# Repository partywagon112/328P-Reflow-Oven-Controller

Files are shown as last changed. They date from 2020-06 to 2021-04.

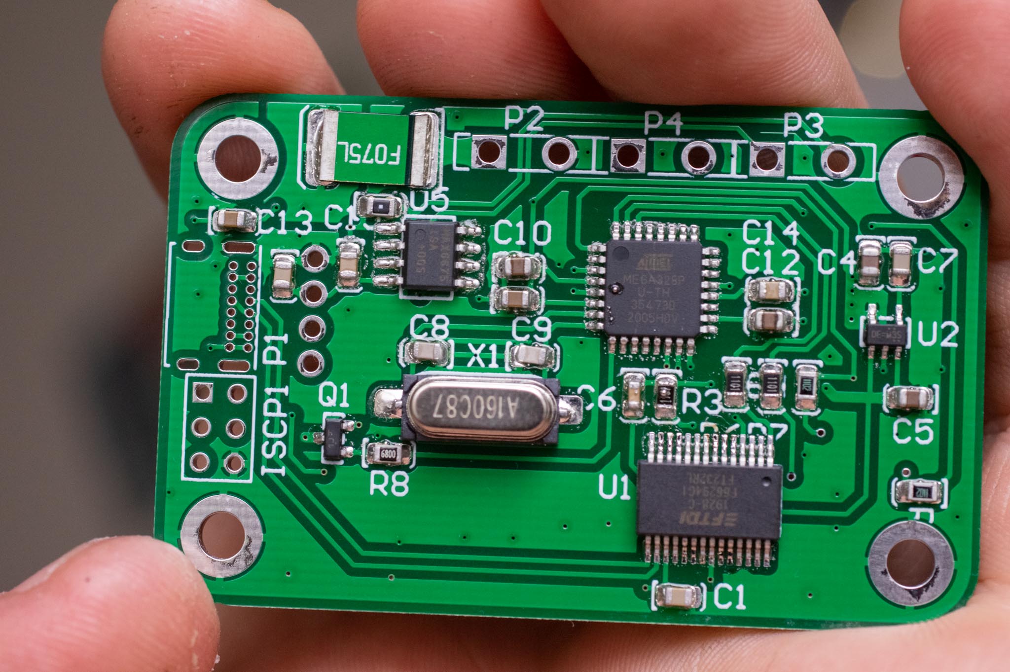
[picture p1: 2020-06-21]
Result.jpg

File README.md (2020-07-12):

# Readme

1. Originally based on ROCKETSCREAM project. Available: https://github.com/rocketscream/Reflow-Oven-Controller
2. PCB designed in altium with the use of the Team Swinburne ts_20 altium library. Available: https://github.com/Team-Swinburne/ts_20-pcb-development
3. Similar to, though heavily modifed from the original project to make it more compact.

# Known Issues and workarounds because there ait going to be another one of these things for a while
- Possible issue with backfeed via USB, cut trace to USB if required. Not generally necessary. 
- USB works C->A, but not C->C. Definite compliance issue.
- Very poor grounding between four corners. Fixed by using a conductive PLA or conductive tape within enclosure.

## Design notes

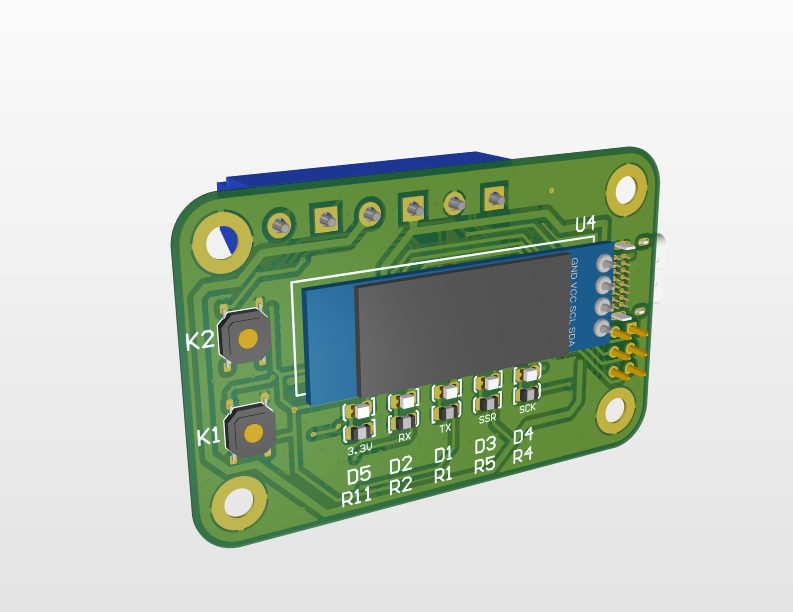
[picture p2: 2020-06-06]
Render.png

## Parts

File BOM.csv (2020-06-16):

Comment | Description | Designator | Footprint | LibRef | Quantity | Digikey Part Number
100nF |  | C1, C6, C13, C14, C15 | 805 | GCM21BR71H104KA37L | 5 | 490-6064-1-ND
4.7uF |  | C3, C11 | 805 | GCM21BR61A475KA37L | 2
1uF |  | C4, C5, C10, C12 | 805 | AC0805KKX7R8BB105 | 4
10nF |  | C7 | 805 | GCM2195C1H103JA16D | 1 | 490-4783-1-ND
22pF |  | C8, C9 | 805 | GRM21A5C2E220JW01D | 2 | 490-5534-1-ND
Orange | Orange LED Indication - Discrete 1.75V 0805 (2012 Metric) | D1 | 0805 LED | SML-211DTT86 | 1 | 511-1291-1-ND
Green | Green LED Indication - Discrete 1.75V 0805 (2012 Metric) | D2 | 0805 LED | SML-210FTT86 | 1 | 511-1285-1-ND
Red | Red LED Indication - Discrete 1.75V 0805 (2012 Metric) | D3, D5 | 0805 LED | SML-210LTT86 | 2 | 511-1286-1-ND
Blue | LED BLUE CLEAR 2012 SMD | D4 | 0805 LED | SML-MN2BCTT86C | 1 | 846-1207-1-ND
0ZCF0100AF2A | PTC RESET FUSE 60V 1A 292 | F1 | 2920 | 0ZCF0100AF2A | 1 | 507-2070-1-ND
TS-1187A-C-D-B | TACTILE SWITCHES SPST 5.10MM X 5.10MM 0.80MM SMD ROHS | K1, K2 | XKB SW-4.5 | TS-1187A-C-D-B | 2
USB4085-GF-A | USB - C (Type - C) USB 2.0 Receptacle Connector 16 Position Through Hole, Right Angle | P1 | USB4085-GF-A | USB4085-GF-A | 1 | 2073-USB4085-GF-ACT-ND
5.08mm |  | P2, P3, P4 | TH 5.08mm Header 1x2 | 1760510000 | 3 | 281-1882-ND
BC817-16LT1 | 300mW BJT NPN Transistor | Q1 | ON SOT-23 BJT | BC817-16LT1 | 1 | BC817-16LT1OSTR-ND
1k |  | R1, R2, R3, R4, R5, R6, R7, R11 | 805 | RC0805FR071KL | 8 | 311-1.00KCRCT-ND
680R |  | R8 | 805 | RC0805FR07680RL | 1 | 311-680CRCT-ND
10k |  | R9, R10 | 805 | RC0805FR0710KL | 2 | 311-10.0KCRCT-ND
0R |  | R12 | 805 | RC0805FR070RL | 1 | 311-0.0CRCT-ND
FT232RL | USB Bridge, USB to UART USB 2.0 UART Interface 28-SSOP | U1 | FTDI 28-SSOP | FT232RL | 1 | 768-1007-1-ND
RT9193-33GB | IC REG LINEAR 3.3V 300MA SOT23-5 | U2 | RICHTEK SOT-23-5 | RT9193-33GB | 1 | 1028-1014-1-ND
ATMEGA 328P-AU | AVR AVR® ATmega Microcontroller IC 8-Bit 20MHz 32KB (16K x 16) FLASH 32-TQFP (7x7) | U3 | ATMEL TQFP-32 | ATMEGA 328P-AU | 1 | ATMEGA328P-AU-ND
SSD1306 128x32 | AU 0.91 IIC I2C OLED LCD Display Module 128x32 for Arduino PIC SSD1306 3.3V~5V" | U4 | IIC 128x32 OLED | SSD1306 128x32 | 1
MAX6675 | IC THERMOCOUP TO DGTL 8-SOIC | U5 | MI 8-SOIC | MAX6675 | 1 | MAX6675ISA+-ND
=Value"" |  | X1 | Abracon HC-49/US | ABLS-16.000MHZ-B4-T | 1 | 535-10226-1-ND

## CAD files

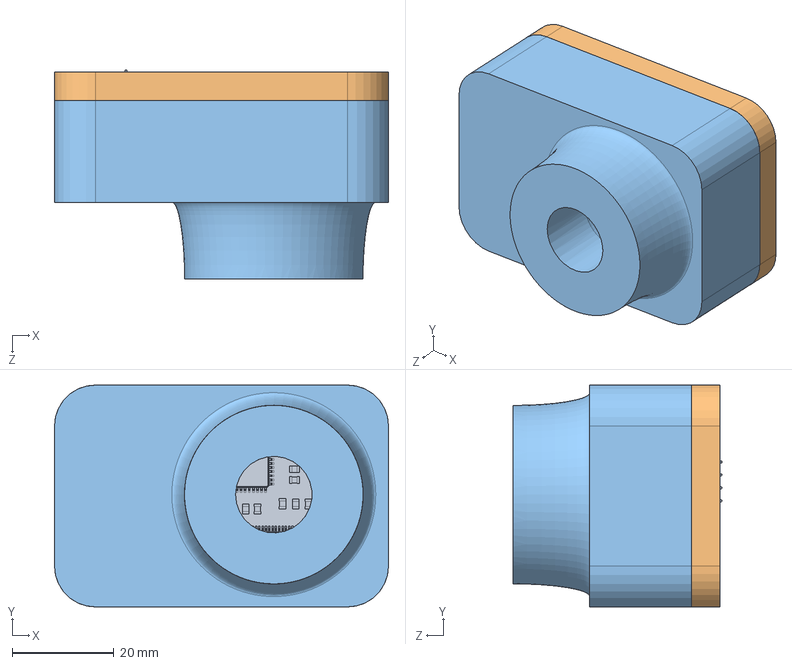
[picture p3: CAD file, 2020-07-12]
Enclosure/Top Level.SLDASM
65.5 x 43.5 x 40.9 mm
PCB

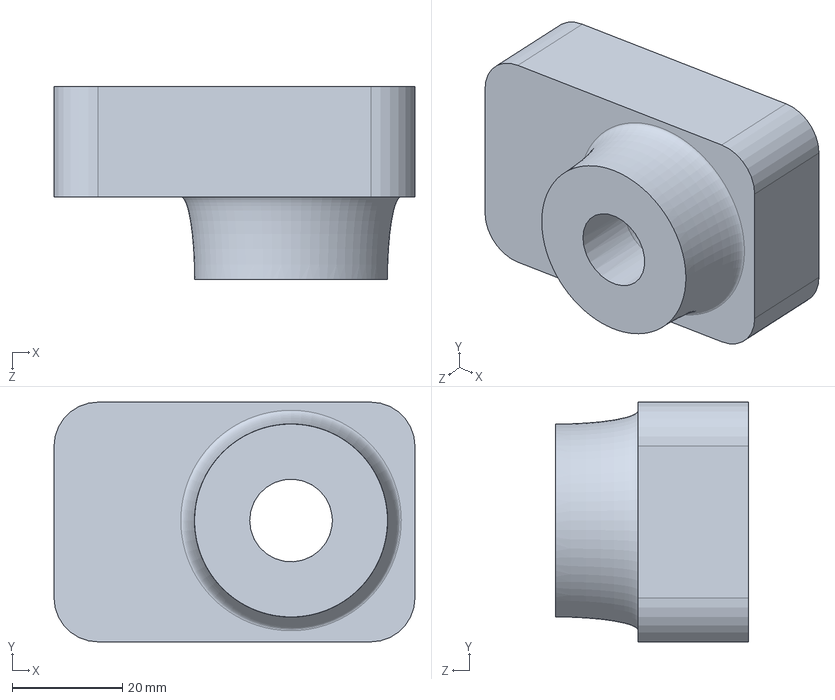
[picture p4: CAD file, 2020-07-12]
Enclosure/Part2.sldprt
65.5 x 43.5 x 35.0 mm

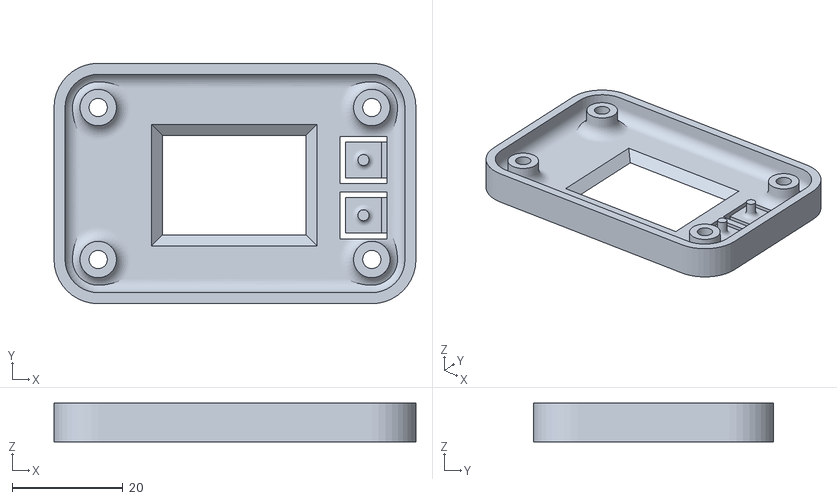
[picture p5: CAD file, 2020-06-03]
Enclosure/STLs/Front.STL
65.5 x 43.5 x 7.00

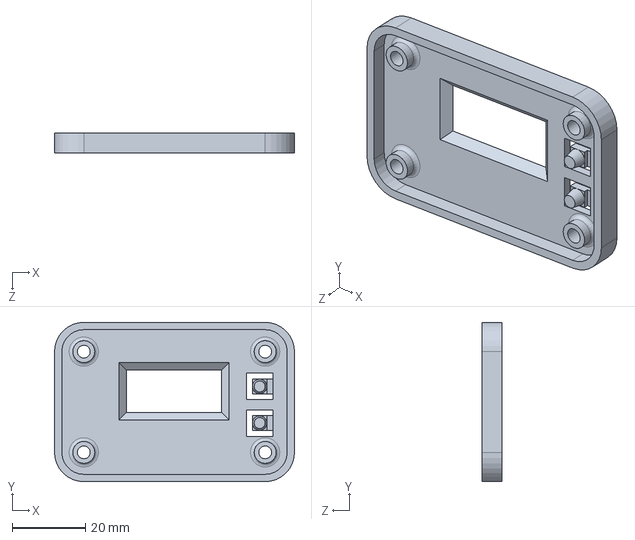
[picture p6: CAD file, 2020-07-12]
Enclosure/Part1.sldprt
65.5 x 43.5 x 5.59 mm

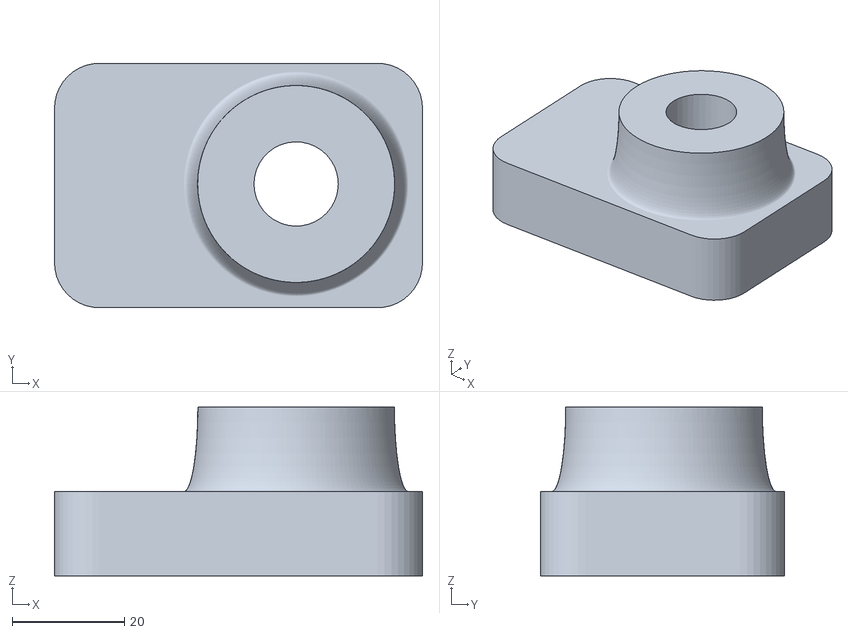
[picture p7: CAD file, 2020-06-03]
Enclosure/STLs/Rear.STL
65.5 x 43.5 x 30.0

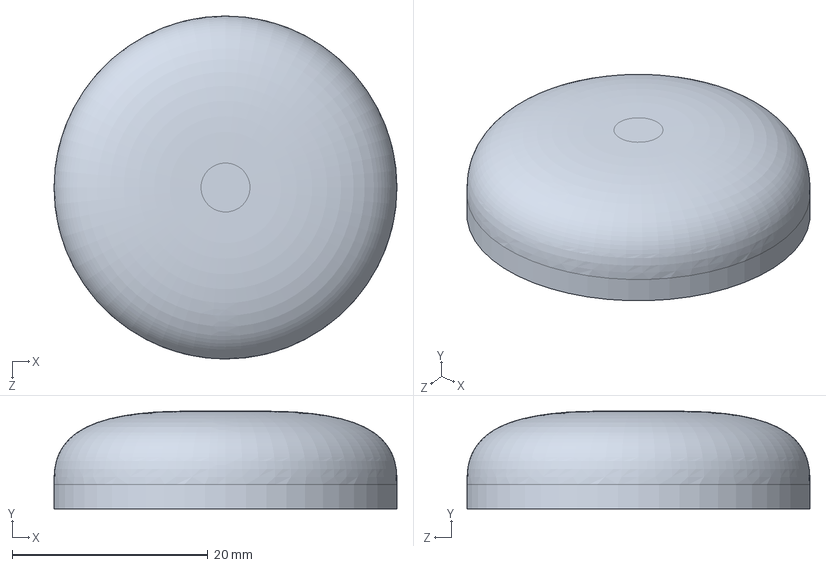
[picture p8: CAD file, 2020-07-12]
Enclosure/Knob Replacement.SLDPRT
35.0 x 10.0 x 35.0 mm

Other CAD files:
Enclosure/STLs/Knob Replacement.STL
Enclosure/STLs/Part1.STL

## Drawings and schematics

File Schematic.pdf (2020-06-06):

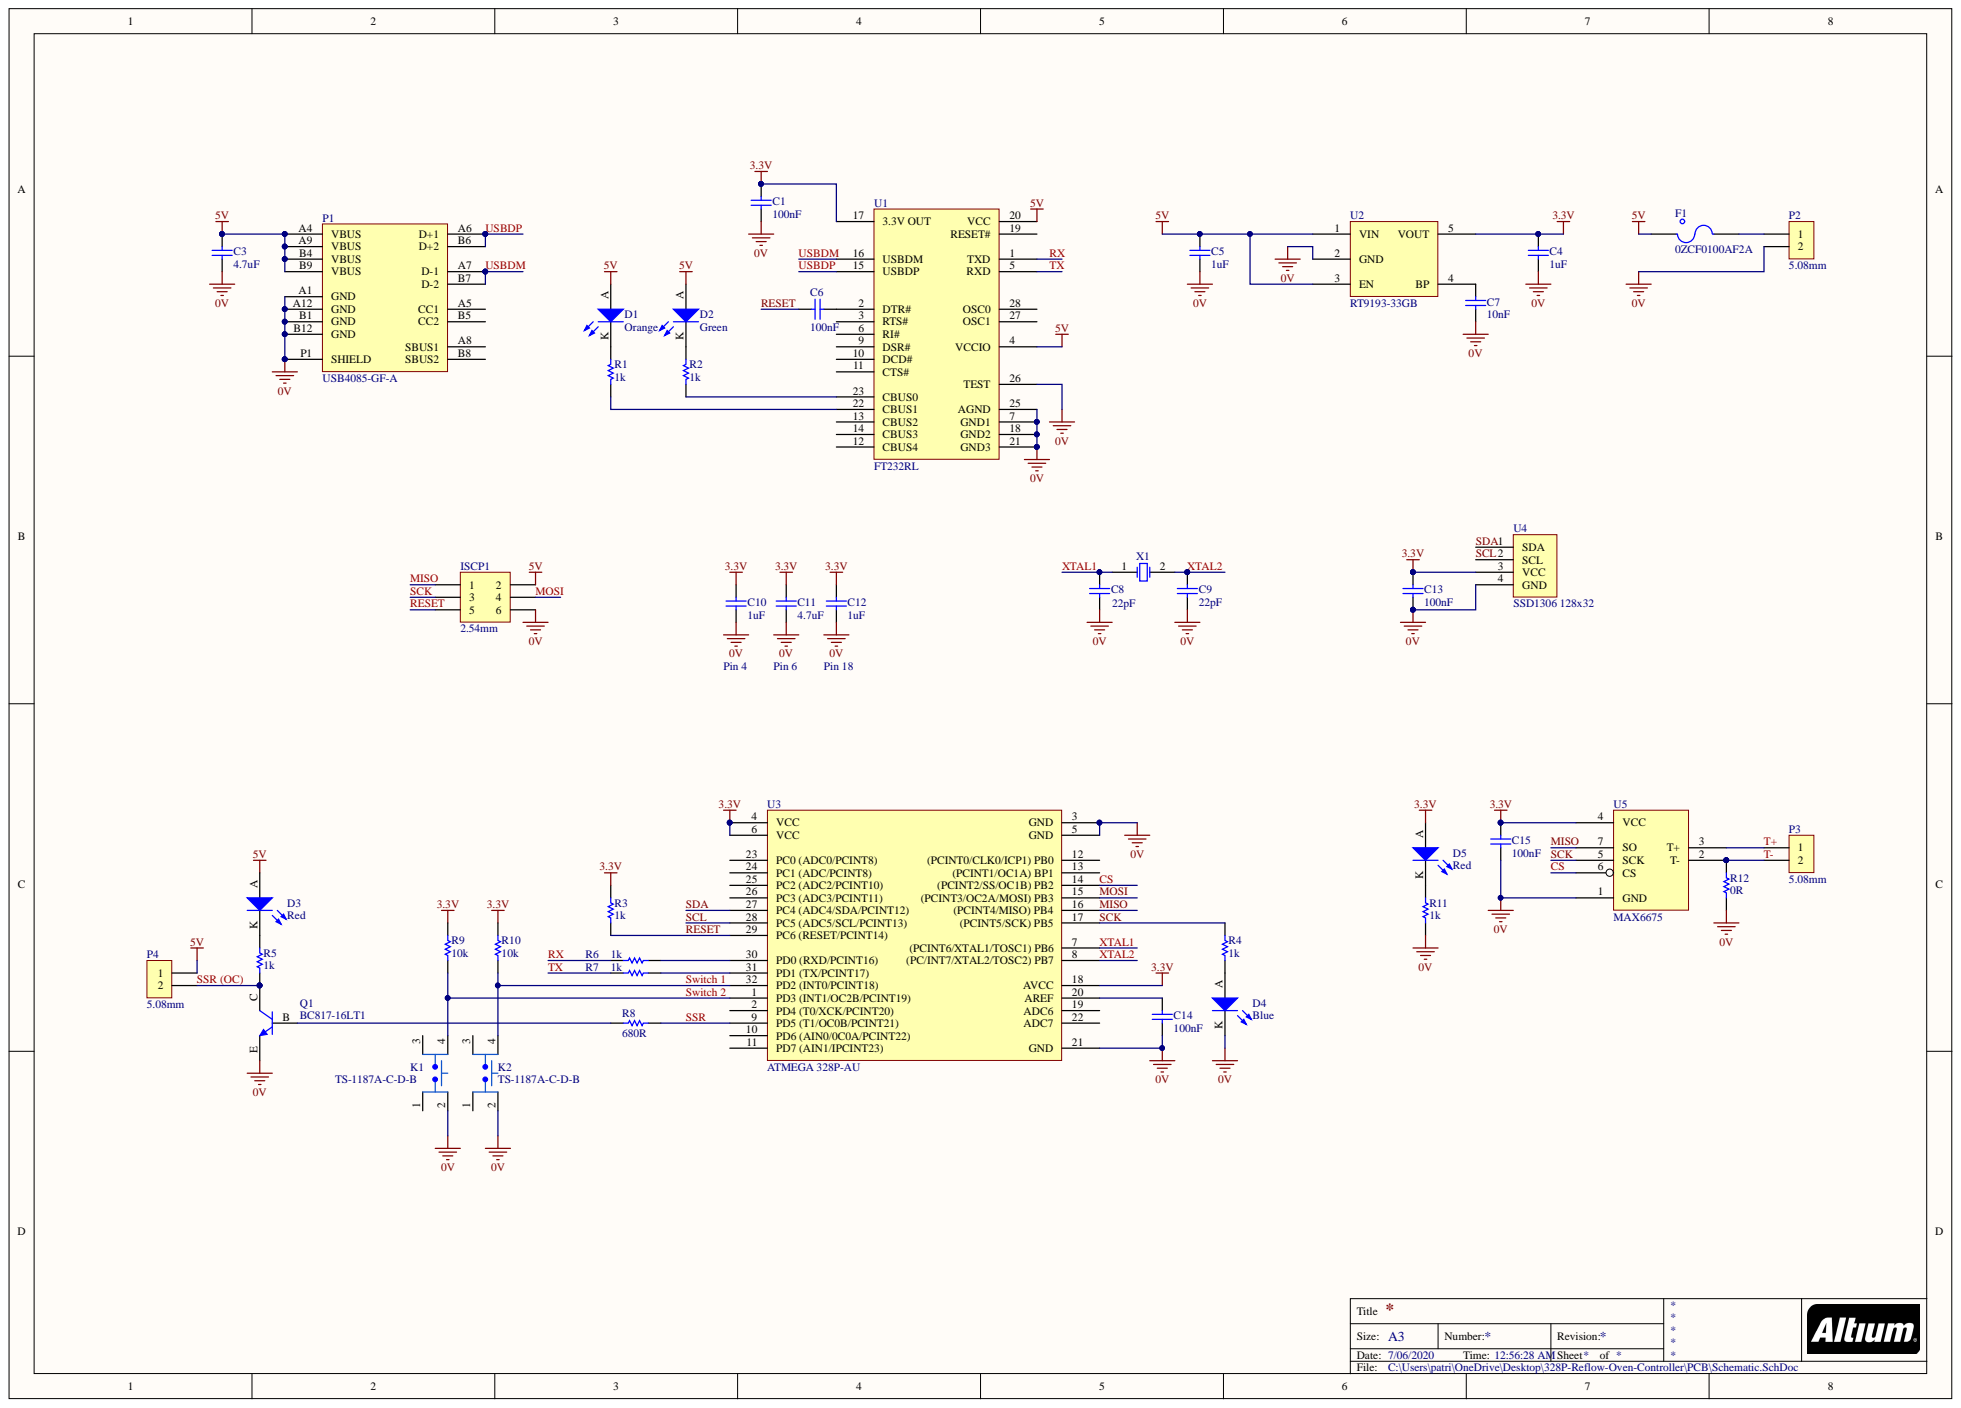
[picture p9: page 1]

SSR 680R | PD4 (T0/XCK/PCINT20) 2

PD7 (AIN1/IPCINT23) 11

* Title | * * * * *

Size: A3 | Number: * | Revision: *
Date: 7/06/2020 Time: 12:56:28 AM | | Sheet * of *

C:\Users\patri\OneDrive\Desktop\328P-Reflow-Oven-Controller\PCB\Schematic.SchDoc

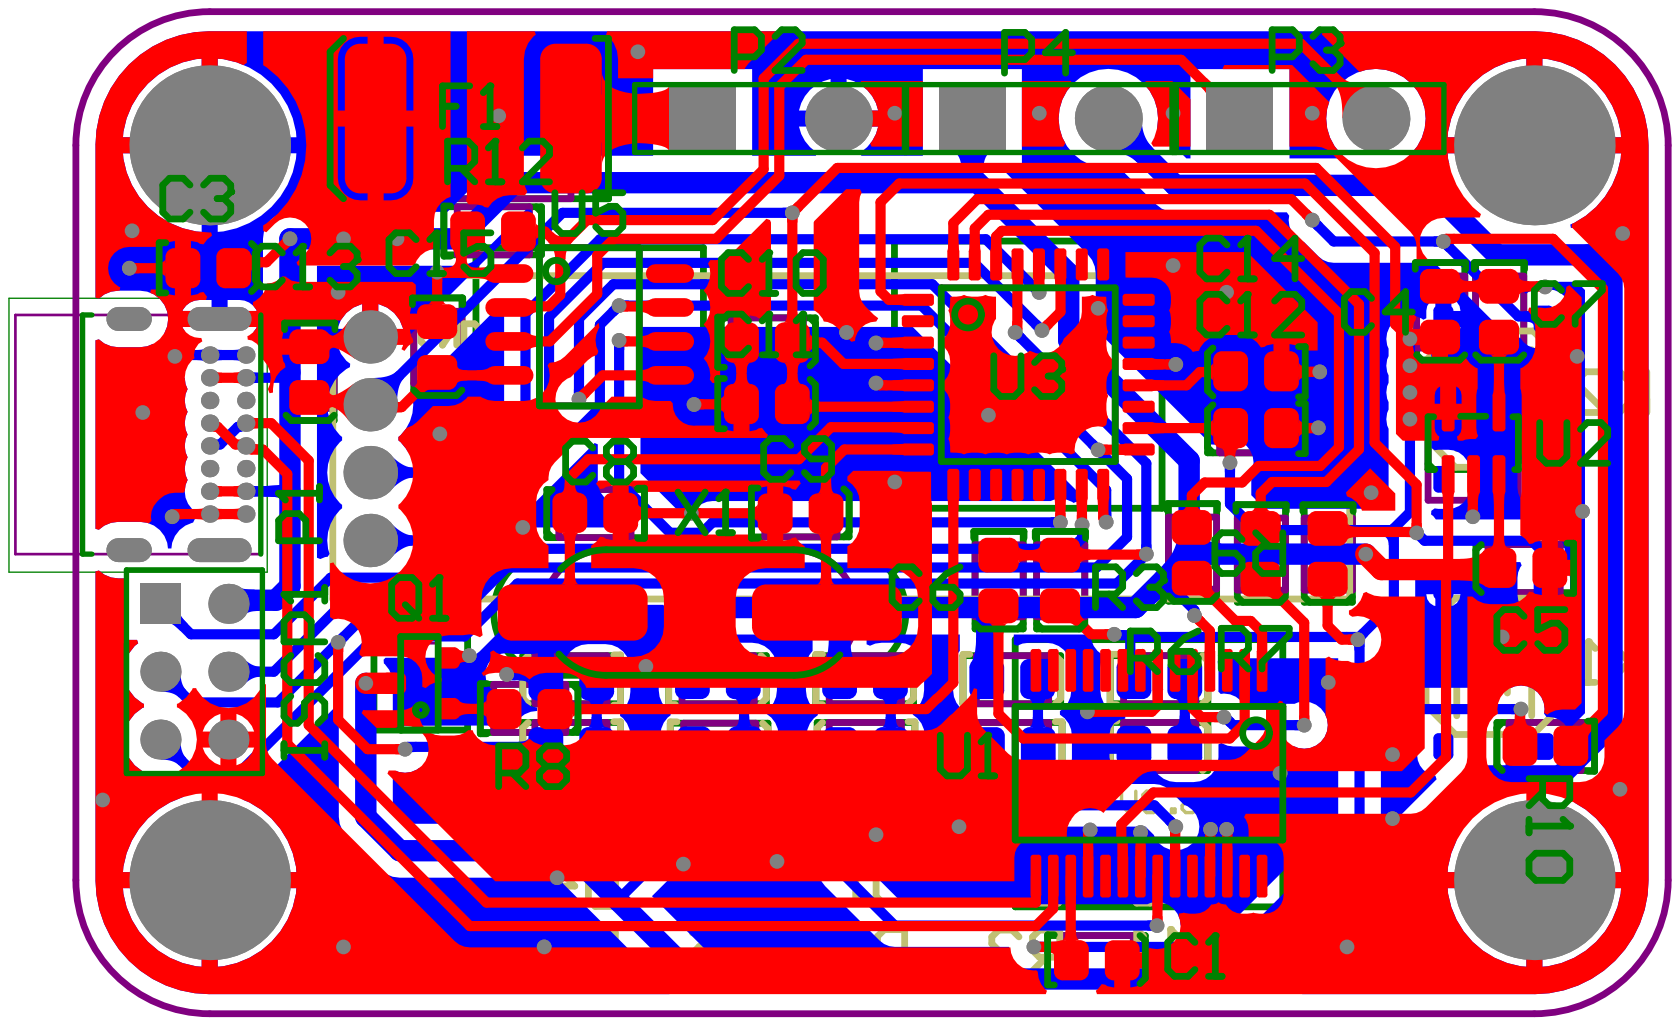
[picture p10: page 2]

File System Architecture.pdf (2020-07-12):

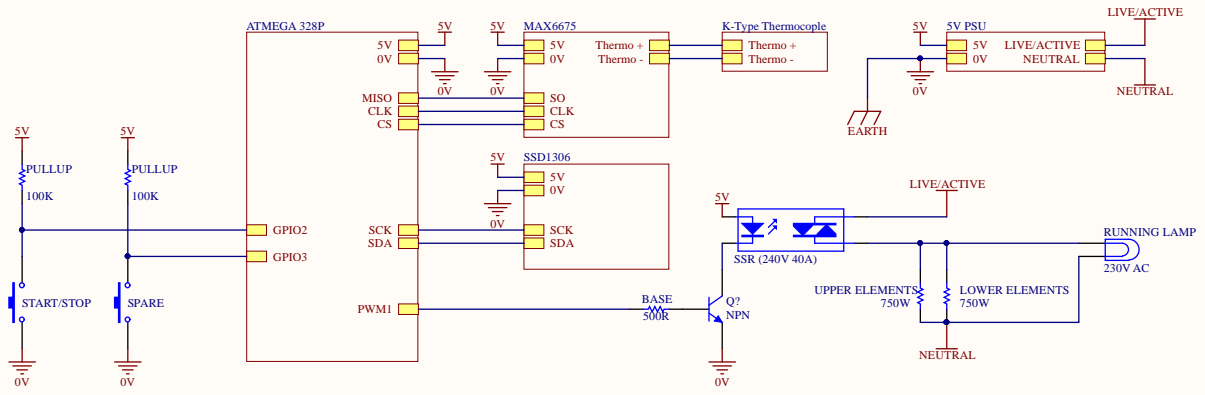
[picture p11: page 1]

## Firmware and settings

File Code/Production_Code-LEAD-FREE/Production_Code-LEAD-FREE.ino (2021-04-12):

/*******************************************************************************
  Title: Reflow Oven Controller
  Version: 1.20
  Date: 26-11-2012
  Company: Rocket Scream Electronics
  Author: Lim Phang Moh
  Website: www.rocketscream.com
  Modified by Patrick Curtain for use with use with attached PCB.

  Temperature (Degree Celcius)                 Magic Happens Here!
  224-|                                               x  x
      |                                            x        x
      |                                         x              x
      |                                      x                    x
  180-|                                   x                          x
      |                              x    |                          |   x
      |                         x         |                          |       x
      |                    x              |                          |
  150-|               x                   |                          |
      |             x |                   |                          |
      |           x   |                   |                          |
      |         x     |                   |                          |
      |       x       |                   |                          |
      |     x         |                   |                          |
      |   x           |                   |                          |
  30 -| x             |                   |                          |
      |<  60 - 90 s  >|<    90 - 120 s   >|<       90 - 120 s       >|
      | Preheat Stage |   Soaking Stage   |       Reflow Stage       | Cool
   0  |_ _ _ _ _ _ _ _|_ _ _ _ _ _ _ _ _ _|_ _ _ _ _ _ _ _ _ _ _ _ _ _ _ _ _ _
                                                                 Time (Seconds)

  Thanks to:

  ==========================================
  ROCKETSCREAM (https://github.com/rocketscream/Reflow-Oven-Controller)
  ==========================================
  Author of the original version of this project.

  ==========================================
  Brett Beauregard (www.brettbeauregard.com)
  ==========================================
  Author of Arduino PID library. On top of providing industry standard PID
  implementation, he gave a lot of help in making this reflow oven controller
  possible using his awesome library.

  ==========================================
  Limor Fried of Adafruit (www.adafruit.com)
  ==========================================
  Author of Arduino MAX6675 library. Adafruit has been the source of tonnes of
  tutorials, examples, and libraries for everyone to learn.

  ==========================================
  Oliver Kraus (https://github.com/olikraus/u8g2)
  ==========================================
  Author of U8G2 library. Increadibly simple to use library, though often the bane
  of my existance.

  Disclaimer
  ==========
  Dealing with high voltage is a very dangerous act! Please make sure you know
  what you are dealing with and have proper knowledge before hand. Your use of
  any information or materials on this reflow oven controller is entirely at
  your own risk, for which we shall not be liable.

  Licences
  ========
  This reflow oven controller hardware and firmware are released under the
  Creative Commons Share Alike v3.0 license
  http://creativecommons.org/licenses/by-sa/3.0/
  You are free to take this piece of code, use it and modify it.
  All we ask is attribution including the supporting libraries used in this
  firmware.
  Huge thankyou to Lim Phang Moh at ROCKETSTREAM for providing such an open platform
  to work on and build these things.

  Required Libraries
  ==================
  - Arduino PID Library:
    >> https://github.com/br3ttb/Arduino-PID-Library
  - MAX6675 Library:
    >> https://github.com/adafruit/MAX6675-library
  - U8G2 Library:
    >> https://github.com/olikraus/u8g2
*******************************************************************************/

// ***** INCLUDES *****
#include <U8g2lib.h>
#include <max6675.h>
#include <PID_v1.h>

// ***** TYPE DEFINITIONS *****
typedef enum REFLOW_STATE
{
  REFLOW_STATE_IDLE,
  REFLOW_STATE_PREHEAT,
  REFLOW_STATE_SOAK,
  REFLOW_STATE_REFLOW,
  REFLOW_STATE_COOL,
  REFLOW_STATE_COMPLETE,
  REFLOW_STATE_TOO_HOT,
  REFLOW_STATE_TIMEOUT,
  REFLOW_STATE_ERROR,
  REFLOW_STATE_INTERACTIVE
} reflowState_t;

typedef enum VERBOSE_STATE
{
  VERBOSE_0,    // No logging except for when REFLOW_STATUS_ON
  VERBOSE_1,    // Log temperature and time every second.
} verboseState_t;

typedef enum INTERACTIVE_STATUS
{
  INTERACTIVE_STATUS_OFF,
  INTERACTIVE_STATUS_ON
} interactiveStatus_t;

typedef enum REFLOW_STATUS
{
  REFLOW_STATUS_OFF,
  REFLOW_STATUS_ON
} reflowStatus_t;

typedef enum SWITCH
{
  SWITCH_NONE,
  SWITCH_1,
  SWITCH_2
} switch_t;

typedef enum DEBOUNCE_STATE
{
  DEBOUNCE_STATE_IDLE,
  DEBOUNCE_STATE_CHECK,
  DEBOUNCE_STATE_RELEASE
} debounceState_t;

// ***** CONSTANTS *****
#define TEMPERATURE_ROOM 50
#define TEMPERATURE_SOAK_MIN 150
#define TEMPERATURE_SOAK_MAX 200
#define TEMPERATURE_REFLOW_MAX 250
#define TEMPERATURE_COOL_MIN 100
#define SENSOR_SAMPLING_TIME 1000
#define SOAK_TEMPERATURE_STEP 5
#define SOAK_MICRO_PERIOD 9000
#define DEBOUNCE_PERIOD_MIN 50
#define REFLOW_TIMEOUT 750

// ***** PID PARAMETERS *****
// ***** PRE-HEAT STAGE *****
#define PID_KP_PREHEAT 100
#define PID_KI_PREHEAT 0.025
#define PID_KD_PREHEAT 20
// ***** SOAKING STAGE *****
#define PID_KP_SOAK 300
#define PID_KI_SOAK 0.05
#define PID_KD_SOAK 250
// ***** REFLOW STAGE *****
#define PID_KP_REFLOW 300
#define PID_KI_REFLOW 0.05
#define PID_KD_REFLOW 350
#define PID_SAMPLE_TIME 1000

// ***** OLED MESSAGES *****
const char* lcdMessagesReflowStatus[] = {
  "Ready",
  "Preheat",
  "Soak",
  "Reflow",
  "Cool",
  "Complete",
  "WAIT, HOT!",
  "Timeout",
  "Error",
  "Interactive"
};

// ***** PIN ASSIGNMENT *****
const int ssrPin = 5;
const int thermocoupleSOPin = 12;
const int thermocoupleCSPin = 10;
const int thermocoupleCLKPin = 13;
const int switch1Pin = 2;
const int switch2Pin = 3;

// ***** PID CONTROL VARIABLES *****
double setpoint;
double input;
double output;
double kp = PID_KP_PREHEAT;
double ki = PID_KI_PREHEAT;
double kd = PID_KD_PREHEAT;
int windowSize;
unsigned long windowStartTime;
unsigned long nextCheck;
unsigned long nextRead;
unsigned long timerSoak;
unsigned long buzzerPeriod;

static bool interactiveTimeoutEnable = true;
static double interactiveTimeout = 1024;
int interactiveTimerSeconds;

// Logging state mode.
verboseState_t verboseState;
// Interactive serial mode.
interactiveStatus_t interactiveStatus;
// Reflow oven controller state machine state variable
reflowState_t reflowState;
// Reflow oven controller status
reflowStatus_t reflowStatus;
// Switch debounce state machine state variable
debounceState_t debounceState;
// Switch debounce timer
long lastDebounceTime;
// Switch press status
switch_t switchStatus;
// Seconds timer
int timerSeconds;

// Specify PID control interface
PID reflowOvenPID(&input, &output, &setpoint, kp, ki, kd, DIRECT);

// Specify OLED interface
U8G2_SSD1306_128X32_UNIVISION_F_SW_I2C oled(U8G2_R2, SCL, SDA, U8X8_PIN_NONE);

// Specify thermocouple interface
MAX6675 thermocouple(thermocoupleCLKPin, thermocoupleCSPin, thermocoupleSOPin);


// ***** FUNCTIONS *****

void stateMachine() {
  // Reflow oven controller state machine
  switch (reflowState)
  {
    case REFLOW_STATE_IDLE:
      reflowStatus = REFLOW_STATUS_OFF;
      // If oven temperature is still above room temperature
      setpoint = 0;
      timerSeconds = 0;
      if (input >= TEMPERATURE_ROOM)
      {
        reflowState = REFLOW_STATE_TOO_HOT;
      }
      else
      {
        // If switch is pressed to start reflow process
        if (switchStatus == SWITCH_1)
        {
          // Send header for CSV file
          Serial.println("Starting:");
          Serial.println("Time, Setpoint, Input, Output");
          // Intialize seconds timer for serial debug information
          timerSeconds = 0;
          // Initialize PID control window starting time
          windowStartTime = millis();
          // Ramp up to minimum soaking temperature
          setpoint = TEMPERATURE_SOAK_MIN;
          // Tell the PID to range between 0 and the full window size
          reflowOvenPID.SetOutputLimits(0, windowSize);
          reflowOvenPID.SetSampleTime(PID_SAMPLE_TIME);
          // Turn the PID on
          reflowOvenPID.SetMode(AUTOMATIC);
          // Proceed to preheat stage
          reflowState = REFLOW_STATE_PREHEAT;
        }
      }
      break;

    case REFLOW_STATE_PREHEAT:
      reflowStatus = REFLOW_STATUS_ON;
      // If minimum soak temperature is achieve
      if (input >= TEMPERATURE_SOAK_MIN)
      {
        // Chop soaking period into smaller sub-period
        timerSoak = millis() + SOAK_MICRO_PERIOD;
        // Set less agressive PID parameters for soaking ramp
        reflowOvenPID.SetTunings(PID_KP_SOAK, PID_KI_SOAK, PID_KD_SOAK);
        // Ramp up to first section of soaking temperature
        setpoint = TEMPERATURE_SOAK_MIN + SOAK_TEMPERATURE_STEP;
        // Proceed to soaking state
        reflowState = REFLOW_STATE_SOAK;
      }
      break;

    case REFLOW_STATE_SOAK:
      // If micro soak temperature is achieved
      if (millis() > timerSoak)
      {
        timerSoak = millis() + SOAK_MICRO_PERIOD;
        // Increment micro setpoint
        setpoint += SOAK_TEMPERATURE_STEP;
        if (setpoint > TEMPERATURE_SOAK_MAX)
        {
          // Set agressive PID parameters for reflow ramp
          reflowOvenPID.SetTunings(PID_KP_REFLOW, PID_KI_REFLOW, PID_KD_REFLOW);
          // Ramp up to first section of soaking temperature
          setpoint = TEMPERATURE_REFLOW_MAX;
          // Proceed to reflowing state
          reflowState = REFLOW_STATE_REFLOW;
        }
      }
      break;

    case REFLOW_STATE_REFLOW:
      // We need to avoid hovering at peak temperature for too long
      // Crude method that works like a charm and safe for the components
      if (input >= (TEMPERATURE_REFLOW_MAX - 5))
      {
        // Set PID parameters for cooling ramp
        reflowOvenPID.SetTunings(PID_KP_REFLOW, PID_KI_REFLOW, PID_KD_REFLOW);
        // Ramp down to minimum cooling temperature
        setpoint = TEMPERATURE_COOL_MIN;
        // Proceed to cooling state
        reflowState = REFLOW_STATE_COOL;
      }
      break;

    case REFLOW_STATE_COOL:
      // If minimum cool temperature is achieve
      if (input <= TEMPERATURE_COOL_MIN)
      {
        buzzerPeriod = millis() + 1000;
        // Turn off reflow process
        reflowStatus = REFLOW_STATUS_OFF;
        // Proceed to reflow Completion state
        reflowState = REFLOW_STATE_COMPLETE;
        Serial.println("Finished");
      }
      break;

    case REFLOW_STATE_COMPLETE:
      if (millis() > buzzerPeriod)
      {
        // Reflow process ended
        reflowState = REFLOW_STATE_IDLE;
        setpoint = 0;
      }
      break;

    case REFLOW_STATE_TOO_HOT:
      // If oven temperature drops below room temperature
      if (input < TEMPERATURE_ROOM)
      {
        // Ready to reflow
        reflowState = REFLOW_STATE_IDLE;
      }
      break;

    case REFLOW_STATE_TIMEOUT:
      Serial.println("RESETTING TO IDLE!");
      reflowState = REFLOW_STATE_IDLE;
      reflowStatus = REFLOW_STATUS_OFF;
      break;

    case REFLOW_STATE_ERROR:
      // If thermocouple problem is still present
      if (isnan(input))
      {
        // Wait until thermocouple wire is connected
        reflowState = REFLOW_STATE_ERROR;
      }
      else
      {
        // Clear to perform reflow process
        reflowState = REFLOW_STATE_IDLE;
      }
      break;
  }
}

void interactiveMode() {
  reflowState = REFLOW_STATE_INTERACTIVE;

  if (interactiveTimeoutEnable) {
    if (interactiveTimerSeconds > interactiveTimeout) {
      setpoint = 0;
      Serial.println("error... timeout");
    }
  }

  while (Serial.available()) {
    char inChar = (char)Serial.read();

    switch (inChar) {
      case 'T':
        reflowStatus = REFLOW_STATUS_ON;
        setpoint = Serial.parseFloat(SKIP_WHITESPACE);

        interactiveTimerSeconds = 0;
        windowStartTime = millis();
        // Tell the PID to range between 0 and the full window size
        reflowOvenPID.SetOutputLimits(0, windowSize);
        reflowOvenPID.SetSampleTime(PID_SAMPLE_TIME);
        reflowOvenPID.SetTunings(PID_KP_SOAK, PID_KI_SOAK, PID_KD_SOAK);
        // Turn the PID on
        reflowOvenPID.SetMode(AUTOMATIC);

        Serial.print("okay... T: ");
        Serial.println(setpoint);
        break;

      case 'D':
        interactiveTimeout = Serial.parseFloat(SKIP_WHITESPACE);
        Serial.print(interactiveTimeout);
        Serial.println("NEW TIMEOUT");
        interactiveTimeoutEnable = true;
        Serial.print("okay... Timeout Enabled... D: ");
        Serial.println(interactiveTimeout);
        break;

      case 'F':
        interactiveTimeoutEnable = false;
        Serial.println("okay... Timeout disabled");
    }
  }
}

void updateInput() {
  // If switch 1 is pressed
  if (switchStatus == SWITCH_1) {
    // If currently reflow process is on going
    if (reflowStatus == REFLOW_STATUS_ON) {
      // Button press is for cancelling
      // Turn off reflow process
      reflowStatus = REFLOW_STATUS_OFF;
      // Reinitialize state machine
      reflowState = REFLOW_STATE_IDLE;
    }
  }

  // Simple switch debounce state machine (for switch #1 (both analog & digital
  // switch supported))
  switch (debounceState)
  {
    case DEBOUNCE_STATE_IDLE:
      // No valid switch press
      switchStatus = SWITCH_NONE;
      // If switch #1 is pressed
      if (digitalRead(switch1Pin) == LOW)
      {
        // Intialize debounce counter
        lastDebounceTime = millis();
        // Proceed to check validity of button press
        debounceState = DEBOUNCE_STATE_CHECK;
      }
      break;

    case DEBOUNCE_STATE_CHECK:
      // If switch #1 is still pressed
      if (digitalRead(switch1Pin) == LOW)
      {
        // If minimum debounce period is completed
        if ((millis() - lastDebounceTime) > DEBOUNCE_PERIOD_MIN)
        {
          // Proceed to wait for button release
          debounceState = DEBOUNCE_STATE_RELEASE;
        }
      }
      // False trigger
      else
      {
        // Reinitialize button debounce state machine
        debounceState = DEBOUNCE_STATE_IDLE;
      }
      break;

    case DEBOUNCE_STATE_RELEASE:
      if (digitalRead(switch1Pin) == HIGH)
      {
        // Valid switch 1 press
        switchStatus = SWITCH_1;
        // Reinitialize button debounce state machine
        debounceState = DEBOUNCE_STATE_IDLE;
      }
      break;
  }
}

void updateRelay() {
  unsigned long now;
  // PID computation and SSR control
  if (reflowStatus == REFLOW_STATUS_ON) {
    now = millis();
    reflowOvenPID.Compute();
    if ((now - windowStartTime) > windowSize) {
      // Time to shift the Relay Window
      windowStartTime += windowSize;
    }
    if (output > (now - windowStartTime))
      digitalWrite(ssrPin, HIGH);
    else
      digitalWrite(ssrPin, LOW);
  }
  // Reflow oven process is off, ensure oven is off

  else
  {
    digitalWrite(ssrPin, LOW);
  }
}

void updateTemperature() {
  // Time to read thermocouple?
  if (millis() > nextRead)
  {
    // Read thermocouple next sampling period
    nextRead += SENSOR_SAMPLING_TIME;
    // Read current temperature
    input = thermocouple.readCelsius();

    // If thermocouple problem detected
    if (isnan(input))
    {
      // Illegal operation
      reflowState = REFLOW_STATE_ERROR;
      reflowStatus = REFLOW_STATUS_OFF;
    }
  }
}

void printDisplay() {
  oled.firstPage();
  do {
    oled.setDrawColor(2);
    oled.setFontMode(0);

    oled.drawStr(0, 10, lcdMessagesReflowStatus[reflowState]);

    if (reflowState == REFLOW_STATE_ERROR) {
      Serial.println("Something's gone wrong!");
      oled.drawStr(0, 30, "TC Error!");
    }
    else {
      // Print current temperature
      oled.setCursor(0, 30);
      oled.print(input);
      if (setpoint > 0) {
        oled.print("->");
        oled.setDrawColor(0);
        oled.print(setpoint);
      }
      oled.setDrawColor(2);
      oled.print("°C");
      if (timerSeconds > 0) {
        char str[20];
        oled.drawStr(oled.getDisplayWidth() - oled.getStrWidth(itoa(timerSeconds, str, 10)), 10, itoa(timerSeconds, str, 3));
        // ^ i'll admit it, this is the most wasteful function in history. WHAT OF IT!
      }
    }
  } while (oled.nextPage());
}

void printLog() {
  Serial.print(timerSeconds);
  Serial.print(", ");
  Serial.print(setpoint);
  Serial.print(", ");
  Serial.print(input);
  Serial.print(", ");
  Serial.println(output);
}

void printVerbosity() {
  if (verboseState == VERBOSE_1) {
    Serial.print("TEMP: ");
    Serial.print(input);
    Serial.print(", ");
    Serial.print("EPOCH: ");
    Serial.println(millis());
  }
}

void timeoutWatchdog() {
  if (reflowStatus == REFLOW_STATUS_ON){
    if (timerSeconds > REFLOW_TIMEOUT){
      reflowStatus = REFLOW_STATUS_OFF;
      reflowState = REFLOW_STATE_TIMEOUT;
      Serial.println("error... timeout");
      timerSeconds = 0;
    }
  }
}

void setup() {
  Serial.println("STARTING");

  // SSR pin initialization to ensure reflow oven is off
  digitalWrite(ssrPin, LOW);

  // Initialise pins
  pinMode(ssrPin, OUTPUT);
  pinMode(switch1Pin, INPUT);
  pinMode(switch2Pin, INPUT);

  // Initialise OLED
  oled.begin();
  oled.setFont(u8g2_font_8x13_mf);
  oled.clearDisplay();
  oled.clearBuffer();
  oled.firstPage();
  oled.enableUTF8Print();

  // Start-up splash screen
  oled.drawStr(0, 10, "I am no longer ");
  oled.drawStr(0, 30, "for lead, No-PB!");
  oled.sendBuffer();
  delay(2500);
  oled.clearBuffer();

  // Initialise serial communications
  verboseState = VERBOSE_0;
  Serial.begin(115200);

  // Print versioning
  Serial.print("COMPILED ");
  Serial.print(__DATE__);
  Serial.print(" ");
  Serial.println(__TIME__);

  // Set window size
  windowSize = 2000;
  // Initialize time keeping variable
  nextCheck = millis();
  // Initialize thermocouple reading variable
  nextRead = millis();
  
  interactiveStatus = INTERACTIVE_STATUS_ON;
}

void loop() {
  // Handles each 1 second interval.
  if (millis() > nextCheck) {
    nextCheck += 1000;
    // If reflow process is on going
    if (reflowStatus == REFLOW_STATUS_ON) {
      // Increase seconds timer for reflow curve analysis
      timerSeconds++;
      // Send temperature and time stamp to serial
      printLog();
    }
    if (reflowState == REFLOW_STATE_IDLE)
      printVerbosity();
  }

  timeoutWatchdog();
  
  if (interactiveStatus == INTERACTIVE_STATUS_ON)
    interactiveMode();
  printDisplay();
  stateMachine();
  updateTemperature();
  updateInput();
  updateRelay();
}

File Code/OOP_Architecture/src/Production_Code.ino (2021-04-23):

/*******************************************************************************
  Required Libraries
  ==================
  - Arduino PID Library:
    >> https://github.com/br3ttb/Arduino-PID-Library
  - MAX6675 Library:
    >> https://github.com/adafruit/MAX6675-library
  - U8G2 Library:
    >> https://github.com/olikraus/u8g2
*******************************************************************************/

// ***** INCLUDES *****
#include <U8g2lib.h>
#include <max6675.h>
#include <PID_v1.h>

// ***** CONSTANTS *****
char SPASH_LINE1[] = {"Reflowinator"};
char SPASH_LINE2[] = {"PCB COOKER V1"};

// ***** PARAMETERS *****
const int TEMPERATURE_PREHEAT_MAX = 150;
const int TEMPERATURE_COOL_MIN = 100;
const int TEMPERATURE_SOAK_STEP = 5;      // Temperature steps in which to increment temperature.

const int LEADED_TEMPERATURE_SOAK_MAX = 180;
const int LEADED_TEMPERATURE_REFLOW_MAX = 224;
const int LEADED_SOAK_PERIOD = 9000;

const int UNLEADED_TEMPERATURE_SOAK_MAX = 200;
const int UNLEADED_TEMPERATURE_REFLOW_MAX = 250;
const int UNLEADED_SOAK_PERIOD = 9000;

const int DEBOUNCE_PERIOD_MIN = 50;       // 50 ms for debouncing input switches.
const int RELAY_UPDATE_PERIOD = 2000;     // Relay PWM Frequency 0.5 Hz.
const int COMPLETE_TIME = 5000;           // 5 seconds to show completed status.

// ***** LIMITS *****
const float TEMPERATURE_SAFE = 50;
const float MAX_TEMP = 1000;
const float MIN_TEMP = -40; 
const int MAX_TIMEOUT = 1000000;          //1000 seconds

// ***** PID PARAMETERS *****
// ***** DEFAULT *****
#define PID_KP_DEFAULT 300
#define PID_KI_DEFAULT 0.05
#define PID_KD_DEFAULT 250
// ***** PRE-HEAT STAGE *****
#define PID_KP_PREHEAT 100
#define PID_KI_PREHEAT 0.025
#define PID_KD_PREHEAT 20
// ***** SOAKING STAGE *****
#define PID_KP_SOAK 300
#define PID_KI_SOAK 0.05
#define PID_KD_SOAK 250
// ***** REFLOW STAGE *****
#define PID_KP_REFLOW 300
#define PID_KI_REFLOW 0.05
#define PID_KD_REFLOW 350

// ***** PIN ASSIGNMENT *****
#define SSR_PIN 5
#define THERMOCOUPLE_SO_PIN 12
#define THERMOCOUPLE_CS_PIN 10
#define THERMOCOUPLE_CLK_PIN 13
#define SWITCH_MODE_PIN 2
#define SWITCH_START_STOP_PIN 3

// ***** TYPE DEFINITIONS *****
typedef enum MACHINE_STATE {
  IDLE_LEADED,
  IDLE_UNLEADED,
  PREHEAT,
  SOAK,
  REFLOW,
  COOL,
  COMPLETE,
  HOT,
  ERROR,
  INTERACTIVE
} machine_state_t;

typedef enum ERROR_STATE {
  ERROR_STATE,
  ERROR_TEMP_SENSOR_FAILURE,
  ERROR_TIMEOUT_EXCEEDED
} error_state_t;

typedef enum VERBOSE_STATE {
  VERBOSE_0,    // No logging except for when REFLOW_STATUS_ON.
  VERBOSE_1,    // Log temperature and time every second.
  VERBOSE_2     // Not quite sure yet.
} verbose_state_t;

typedef enum DEBOUNCE_STATE {
  DEBOUNCE_STATE_IDLE,
  DEBOUNCE_STATE_CHECK,
  DEBOUNCE_STATE_RELEASE
} debounce_state_t;

typedef enum HEATER_STATE {
  HEATER_ACTIVE,
  HEATER_DISABLE
} heater_state_t;

// ***** OLED MESSAGES *****
const char* message_machine_state[] = {
  "Leaded",
  "Unleaded",
  "Preheat",
  "Soak",
  "Reflow",
  "Cool",
  "Complete",
  "Wait, Hot!",
  "Error",
  "Interactive"
};

const char* message_error_status[] = {
  "Safe",
  "Sensor Fail",
  "Timeout"
};

// ***** OBJECTS *****

// CLASS: SWITCH
// 
// Object describiing a physically button interface
// - Use update_switch() with program loop to constantly poll the state of the button,
//   and perform debouncing function.
// - Use get_switch() to access the state of the switch. 
// 
class Switch {
  public:
    Switch::Switch(){}
    Switch::Switch(int i_switch_pin){
      switch_pin = i_switch_pin;
    }

    void Switch::update_switch(){
      switch_state = 0;

      switch (debounce_state){
        case DEBOUNCE_STATE_IDLE:
          switch_state = 0;
          if (digitalRead(switch_pin) == LOW){
            last_debounce_time = millis();
            debounce_state = DEBOUNCE_STATE_CHECK;
          }
          break;

        case DEBOUNCE_STATE_CHECK:
          if (digitalRead(switch_pin) == LOW){
            if ((millis() - last_debounce_time) > DEBOUNCE_PERIOD_MIN){
              debounce_state = DEBOUNCE_STATE_RELEASE;
            } 
          }
          break;
        
        case DEBOUNCE_STATE_RELEASE:
          if (digitalRead(switch_pin) == HIGH){
            switch_state = 1;
            debounce_state = DEBOUNCE_STATE_IDLE;
          }
          break;
      }
    }

    bool Switch::get_state(){
      return switch_state;
    }

  private:
    int switch_pin;
    bool switch_state;
    debounce_state_t debounce_state;
    unsigned long last_debounce_time;
};

// CLASS: HEATER INTERFACE
// 
// Object describiing the relation of the heating element and the temperature sensor. Maintains
// internal PID controller to control the duty cycle of the temperature sensor.
// - Use update_relay() within program loop to constantly update the solid state relay used
//   to control the heating element. 
// - Use update_temperature() within program loop to constatly update the current measured temperature
//   and check the validity of the sensors measurements.
// - Use configure_PID() to set the parameters of the PID. 
// 
class Heater{
  public:
    Heater::Heater(const int i_ssr_relay_pin, int i_thermocouple_clk_pin, int i_thermocouple_cs_pin, int i_thermocouple_so_pin) : 
      thermocouple(i_thermocouple_clk_pin, i_thermocouple_cs_pin, i_thermocouple_so_pin), 
      heater_pid(&input, &output, &setpoint, kp, ki, kd, DIRECT) {
      ssr_relay_pin = i_ssr_relay_pin;

      pinMode(ssr_relay_pin, OUTPUT);
      digitalWrite(ssr_relay_pin, LOW);

      heater_state = HEATER_DISABLE;

      heater_pid.SetTunings(PID_KP_DEFAULT, PID_KI_DEFAULT, PID_KD_DEFAULT);
      heater_pid.SetOutputLimits(0, RELAY_UPDATE_PERIOD);
      heater_pid.SetMode(AUTOMATIC);  
    }

    bool Heater::update_temperature(){
      bool safe = false;
      if (millis() - last_set_time > MAX_TIMEOUT){
        timeout_failure_flag = ERROR_TIMEOUT_EXCEEDED;
        safe = false;
      }

      double thermocouple_temperature = thermocouple.readCelsius();
      if (isnan(thermocouple_temperature) || thermocouple_temperature > MAX_TEMP || thermocouple_temperature < MIN_TEMP) {
        temp_sensor_failure_flag = ERROR_TEMP_SENSOR_FAILURE;
        safe = false;
      } else {
        input = thermocouple_temperature;
        temp_sensor_failure_flag = ERROR_STATE;
        safe = true;
      }

      return safe;
    }

    void Heater::update_relay(){
      heater_pid.Compute();
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

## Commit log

2020-05-25 Added gerber, and submitted first order, also face plate
    [328P Oven Controller.PrjPcb, 328P Oven Controller.xls, Faicure.SLDPRT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]
2020-06-03 Added draft enclosure
    [Faicure.SLDPRT, Front.STL, Part1.sldprt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]
2020-06-06 Added some documentation
    [BOM.csv, Session Data.xlsx]
2020-06-16 Pretty major software update for app. specific
    [328P Oven Controller.PrjPcb, BOM.csv, Part1.sldprt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]
2020-06-21 Updates to code for easy CSV output, new python script to pull curves off quickly, general tidyup
    [BOM.xls, SAVE - 20200621-145226.csv]
2020-06-21 Also added a nice little photo :D
    [Part2.sldprt, Pedal Assembly.SLDASM, Top Level.SLDASM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]
2020-07-12 Added additional programme/interactive mode
    [Knob Replacement.SLDPRT, Knob Replacement.STL, Part1.STL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]
2021-04-12 Reworked code into OOPish style, still needs work
    [Production_Code-LEAD-FREE.ino, Production_Code.ino]
